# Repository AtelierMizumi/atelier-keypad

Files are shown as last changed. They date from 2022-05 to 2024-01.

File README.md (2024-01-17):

# Atelier6K Keypad Project
The Atelier6K is a 6 keys keypad with 3 additional button designed for playing osu! or to be used as small macropad
+ Hotswapable
+ Per switch RGB + Bottom Case RGB
+ Acrylic Case
+ QMK Firmware with VIA compable (Keybinding, Light Control ...)

# Preview images

## PCB front view



## PCB back view



## Case



+ 7$: Fuse, Led, Switch, Bolts, Keycap, USB C Female connector, Rubber Feet
+ 5$: Atmega32u4
+ 5$: Acrylic Case
+ 3$: PCB printing
+ 2$: USB Cable

$40 to be expected

# Sketch



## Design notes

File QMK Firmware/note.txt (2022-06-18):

Để tự compile cái firmware này:
#1 Copy paste "atelier6k" vào mục keyboards của nơi chứa QMK Firmware
# Vào QMK MSYS gõ qmk compile -kb atelier6k -km default

Nếu biết tự làm firmware rồi, chắc không cần chỉ dẫn thêm. Good Luck!

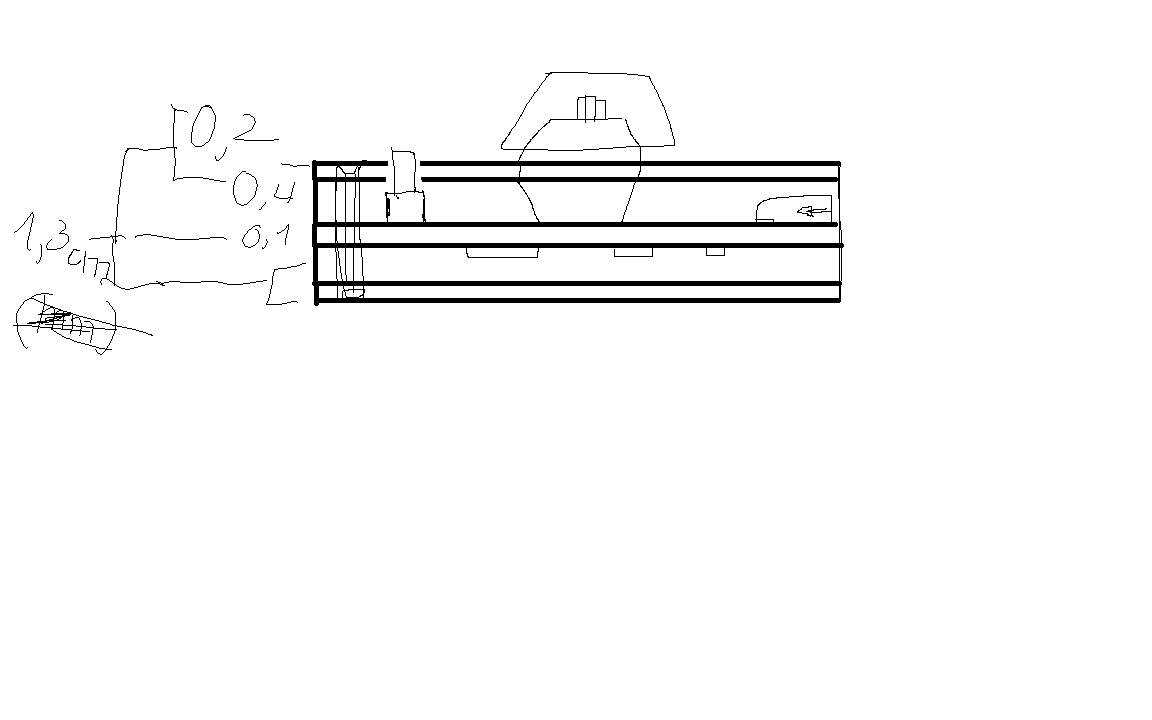
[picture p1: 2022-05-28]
basic sketch lmao.jpg

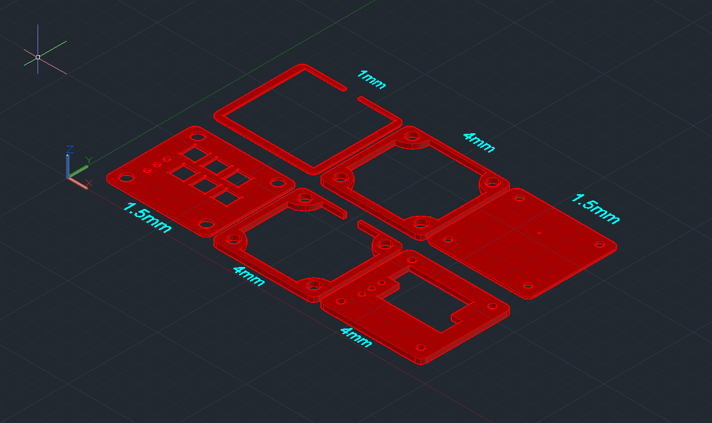
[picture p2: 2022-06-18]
attachment.png

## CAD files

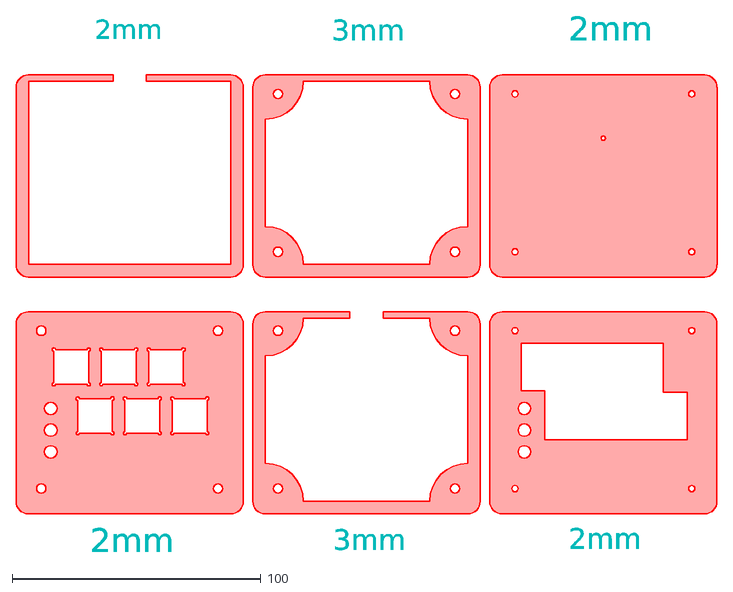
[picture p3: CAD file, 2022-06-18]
Case/Case-Cutout.dxf
2mm
3mm

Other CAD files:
Case/Drawing1.dwg
Case/Case-Cutout.dwg

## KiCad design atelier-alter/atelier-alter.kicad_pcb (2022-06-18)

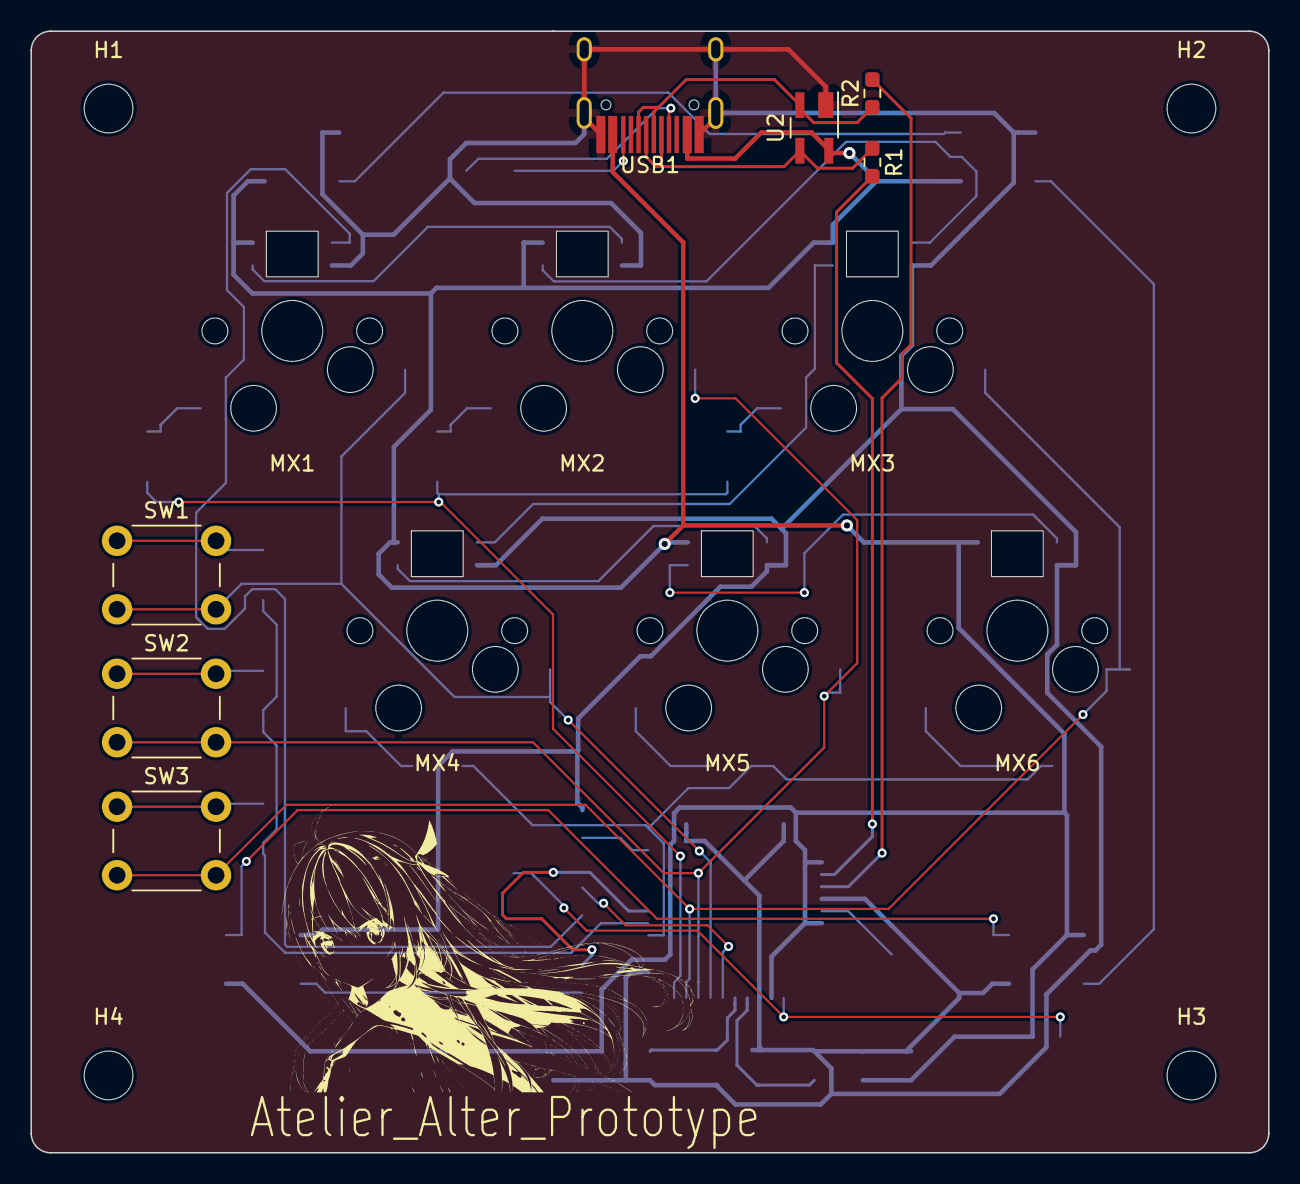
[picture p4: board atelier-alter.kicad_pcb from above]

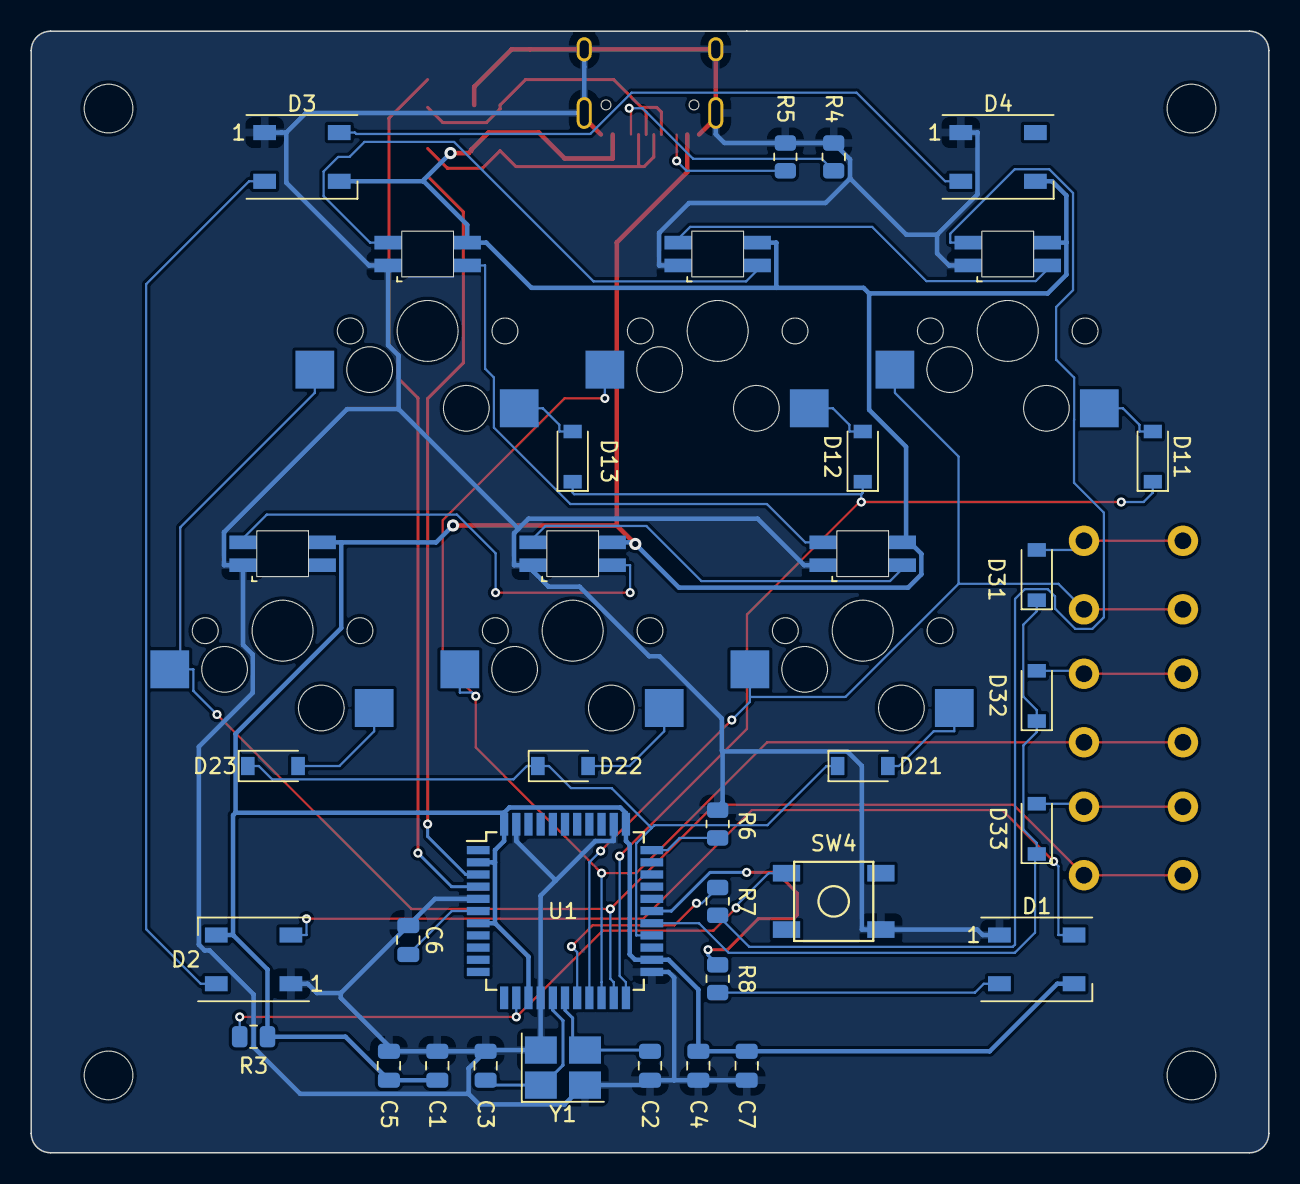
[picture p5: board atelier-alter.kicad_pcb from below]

Board: 2 copper layers, 81.3 x 73.7 mm, 47 parts (29 on the bottom side), 40 nets.

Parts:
Atorie': LOGO; Alter_Drawing
C1, C4, C5: 0.1uF; C_0805_2012Metric
C2, C3: 22pF; C_0805_2012Metric
C6: 1uF; C_0805_2012Metric
C7: 10uF; C_0805_2012Metric
D1, D2, D3, D4: SK6812 / WS2812B; LED_WS2812B_PLCC4_5.0x5.0mm_P3.2mm
D11, D12, D13, D21, D22, D23, D31, D32, D33: SOD-123; D_SOD-123
H1, H2, H3, H4: MountingHole; MountingHole_3.2mm_M3_ISO7380
MX1, MX2, MX3, MX4, MX5, MX6: Cherry_MX_Cherry_MX_RGB; Cherry-MX_PCB-Mounted_LTST-A683CEGBW_Kailh_Socket
R1, R2: 22; R_0603_1608Metric_Pad0.98x0.95mm_HandSolder
R3, R6: 10k; R_0805_2012Metric
R4, R5: 5.1k; R_0805_2012Metric
R7, R8: 300; R_0805_2012Metric
SW1, SW2, SW3: SW_DPST; SW_PUSH_6mm_H13mm
SW4: RESET; SKQG-1155865
U1: ATmega32U4-A; TQFP-44_10x10mm_P0.8mm
U2: PRTR5V0U2X; SOT-143_Handsoldering
USB1: HRO-TYPE-C-31-M-12; HRO-TYPE-C-31-M-12-HandSoldering
Y1: 16Mhz; Crystal_SMD_3225-4Pin_3.2x2.5mm_HandSoldering

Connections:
+5V: C1.1, C4.1, C5.1, C7.1, D1.3 (VDD), D2.3 (VDD), D3.3 (VDD), D4.3 (VDD), MX1.4 (VCC), MX2.4 (VCC), MX3.4 (VCC), MX4.4 (VCC), MX5.4 (VCC), MX6.4 (VCC), R3.2, U1.2 (UVCC), U1.7 (VBUS), U1.14 (VCC), U1.24 (AVCC), U1.34 (VCC), U1.44 (AVCC), U2.4 (VCC), USB1.2 (VBUS), USB1.11 (VBUS)
BackRGB: D1.2 (DIN), R8.2
COL1: MX1.5 (SW1), MX4.5 (SW1), SW1.2, U1.19 (PD1)
COL2: MX2.5 (SW1), MX5.5 (SW1), SW2.2, U1.20 (PD2)
COL3: MX3.5 (SW1), MX6.5 (SW1), SW3.2, U1.21 (PD3)
D12: MX3.3 (DOUT), MX4.2 (DIN)
D+: R2.1, U2.2 (IO1), USB1.6 (DP1), USB1.8 (DP2)
D-: R1.1, U2.3 (IO2), USB1.5 (DN2), USB1.7 (DN1)
GND: C1.2, C2.1, C3.1, C4.2, C5.2, C6.1, C7.2, D1.1 (VSS), D2.1 (VSS), D3.1 (VSS), D4.1 (VSS), MX1.1 (GND), MX2.1 (GND), MX3.1 (GND), MX4.1 (GND), MX5.1 (GND), MX6.1 (GND), R4.1, R5.1, R6.2, SW4.1, U1.5 (UGND), U1.15 (GND), U1.23 (GND), U1.35 (GND), U1.43 (GND), U2.1 (GND), USB1.1 (GND), USB1.12 (GND), USB1.13 (SHIELD), Y1.2, Y1.4
InKeyRGB: MX1.2 (DIN), R7.2
unnamed: C2.2, U1.17 (XTAL1), Y1.3
unnamed: C3.2, U1.16 (XTAL2), Y1.1
unnamed: C6.2, U1.6 (UCAP)
unnamed: D1.4 (DOUT), D2.2 (DIN)
unnamed: D2.4 (DOUT), D3.2 (DIN)
unnamed: D3.4 (DOUT), D4.2 (DIN)
unnamed: D11.2 (A), MX1.6 (SW2)
unnamed: D12.2 (A), MX2.6 (SW2)
unnamed: D13.2 (A), MX3.6 (SW2)
unnamed: D21.2 (A), MX4.6 (SW2)
unnamed: D22.2 (A), MX5.6 (SW2)
unnamed: D23.2 (A), MX6.6 (SW2)
unnamed: D31.2 (A), SW1.1
unnamed: D32.2 (A), SW2.1
unnamed: D33.2 (A), SW3.1
unnamed: MX1.3 (DOUT), MX2.2 (DIN)
unnamed: MX2.3 (DOUT), MX3.2 (DIN)
unnamed: MX4.3 (DOUT), MX5.2 (DIN)
unnamed: MX5.3 (DOUT), MX6.2 (DIN)
unnamed: R1.2, U1.3 (D-)
unnamed: R2.2, U1.4 (D+)
unnamed: R3.1, SW4.2, U1.13 (~RESET)
unnamed: R4.2, USB1.4 (CC1)
unnamed: R5.2, USB1.10 (CC2)
unnamed: R6.1, U1.33 (~HWB/PE2)
unnamed: R7.1, U1.18 (PD0)
unnamed: R8.1, U1.28 (PB4)
ROW1: D11.1 (K), D12.1 (K), D13.1 (K), U1.22 (PD5)
ROW2: D21.1 (K), D22.1 (K), D23.1 (K), U1.26 (PD6)
ROW3: D31.1 (K), D32.1 (K), D33.1 (K), U1.27 (PD7)

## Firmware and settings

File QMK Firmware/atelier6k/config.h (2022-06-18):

/*
Copyright 2012 Jun Wako <wakojun@gmail.com>

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
You should have received a copy of the GNU General Public License
along with this program.  If not, see <http://www.gnu.org/licenses/>.
*/

#pragma once

#include "config_common.h"

/* USB Device descriptor parameter */
#define VENDOR_ID       0xFEED
#define PRODUCT_ID      0x6060
#define DEVICE_VER      0x0001
#define MANUFACTURER    thuanc177
#define PRODUCT         alter6k
#define DESCRIPTION     The Alter6k keypad

/* key matrix size */
#define MATRIX_ROWS 3
#define MATRIX_COLS 3

/* key matrix pins */
#define MATRIX_ROW_PINS { D5, D6, D7 }
#define MATRIX_COL_PINS { D1, D2, D3 }
#define UNUSED_PINS { B0, B1, B2, B3, B5, B6, B7, C6, C6, D4, E6, F0, F1, F4, F5, F6, F7  }

/* COL2ROW or ROW2COL */
#define DIODE_DIRECTION COL2ROW

/* number of backlight levels */
#define BACKLIGHT_PIN B4
#define BACKLIGHT_LEVELS 8

/* Set 0 if debouncing isn't needed */
#define DEBOUNCING_DELAY 5

/* Mechanical locking support. Use KC_LCAP, KC_LNUM or KC_LSCR instead in keymap */
#define LOCKING_SUPPORT_ENABLE

/* Locking resynchronize hack */
#define LOCKING_RESYNC_ENABLE

/* key combination for command */
#define IS_COMMAND() ( \
    keyboard_report->mods == (MOD_BIT(KC_LSHIFT) | MOD_BIT(KC_RSHIFT)) \
)

/* prevent stuck modifiers */
#define PREVENT_STUCK_MODIFIERS

/*Extra stuffs I added myself */
#define USB_POLLING_INTERVAL_MS 1
#define FORCE_NKRO
#define BOOTMAGIC_LITE_ROW 0
#define BOOTMAGIC_LITE_COLUMN 0

/*RGB config and shits*/
#define RGB_DI_PIN D0
#define RGBLIGHT_ANIMATIONS
#define RGBLED_NUM 6
#define RGBW
#define RGBLIGHT_HUE_STEP 12
#define RGBLIGHT_SAT_STEP 25
#define RGBLIGHT_VAL_STEP 8
#define RGBLIGHT_EFFECT_BREATHING
#define RGBLIGHT_EFFECT_RAINBOW_MOOD
#define RGBLIGHT_EFFECT_RAINBOW_SWIRL
#define RGBLIGHT_EFFECT_GRADIENT
#define RGBLIGHT_DEFAULT_MODE RGBLIGHT_MODE_RAINBOW_MOOD

#define USB_MAX_POWER_CONSUMPTION 500

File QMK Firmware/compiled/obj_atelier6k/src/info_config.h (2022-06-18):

// Copyright 2022 QMK
// SPDX-License-Identifier: GPL-2.0-or-later

/*******************************************************************************
  88888888888 888      d8b                .d888 d8b 888               d8b
      888     888      Y8P               d88P"  Y8P 888               Y8P
      888     888                        888        888
      888     88888b.  888 .d8888b       888888 888 888  .d88b.       888 .d8888b
      888     888 "88b 888 88K           888    888 888 d8P  Y8b      888 88K
      888     888  888 888 "Y8888b.      888    888 888 88888888      888 "Y8888b.
      888     888  888 888      X88      888    888 888 Y8b.          888      X88
      888     888  888 888  88888P'      888    888 888  "Y8888       888  88888P'
                                                        888                 888
                                                        888                 888
                                                        888                 888
     .d88b.   .d88b.  88888b.   .d88b.  888d888 8888b.  888888 .d88b.   .d88888
    d88P"88b d8P  Y8b 888 "88b d8P  Y8b 888P"      "88b 888   d8P  Y8b d88" 888
    888  888 88888888 888  888 88888888 888    .d888888 888   88888888 888  888
    Y88b 888 Y8b.     888  888 Y8b.     888    888  888 Y88b. Y8b.     Y88b 888
     "Y88888  "Y8888  888  888  "Y8888  888    "Y888888  "Y888 "Y8888   "Y88888
         888
    Y8b d88P
     "Y88P"
*******************************************************************************/

#pragma once

#ifndef BACKLIGHT_PIN
#   define BACKLIGHT_PIN B4
#endif // BACKLIGHT_PIN

#ifndef DEVICE_VER
#   define DEVICE_VER 0x0001
#endif // DEVICE_VER

#ifndef DESCRIPTION
#   define DESCRIPTION "atelier6k"
#endif // DESCRIPTION

#ifndef DIODE_DIRECTION
#   define DIODE_DIRECTION COL2ROW
#endif // DIODE_DIRECTION

#ifndef MANUFACTURER
#   define MANUFACTURER thuanc177
#endif // MANUFACTURER

#ifndef RGB_DI_PIN
#   define RGB_DI_PIN D0
#endif // RGB_DI_PIN

#ifndef RGBLED_NUM
#   define RGBLED_NUM 6
#endif // RGBLED_NUM

#ifndef RGBLIGHT_HUE_STEP
#   define RGBLIGHT_HUE_STEP 12
#endif // RGBLIGHT_HUE_STEP

#ifndef RGBLIGHT_SAT_STEP
#   define RGBLIGHT_SAT_STEP 25
#endif // RGBLIGHT_SAT_STEP

#ifndef RGBLIGHT_VAL_STEP
#   define RGBLIGHT_VAL_STEP 8
#endif // RGBLIGHT_VAL_STEP

#ifndef PRODUCT
#   define PRODUCT alter6k
#endif // PRODUCT

#ifndef PRODUCT_ID
#   define PRODUCT_ID 0x6060
#endif // PRODUCT_ID

#ifndef VENDOR_ID
#   define VENDOR_ID 0xFEED
#endif // VENDOR_ID

#ifndef USB_MAX_POWER_CONSUMPTION
#   define USB_MAX_POWER_CONSUMPTION 500
#endif // USB_MAX_POWER_CONSUMPTION

#ifndef USB_POLLING_INTERVAL_MS
#   define USB_POLLING_INTERVAL_MS 1
#endif // USB_POLLING_INTERVAL_MS

#ifndef MATRIX_COLS
#   define MATRIX_COLS 3
#endif // MATRIX_COLS

#ifndef MATRIX_ROWS
#   define MATRIX_ROWS 3
#endif // MATRIX_ROWS


#ifndef MATRIX_COL_PINS
#   define MATRIX_COL_PINS { D1, D2, D3 }
#endif // MATRIX_COL_PINS


#ifndef MATRIX_ROW_PINS
#   define MATRIX_ROW_PINS { D5, D6, D7 }
#endif // MATRIX_ROW_PINS

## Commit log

2022-05-25 add main things
    [atelier-alter.kicad_pcb, atelier-alter.kicad_sch]
2022-05-26 da route thu nghiem xong xuoi
    [atelier-alter.kicad_pcb]
2022-05-27 redrawn lan 3, them vai chuc nang
    [atelier-alter-27-5-2022.dsn, atelier-alter-28-5-2022.dsn, atelier-alter.kicad_pcb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]
2022-05-27 tham khao them tu board vcl6k
2022-05-27 kaka, rat manh
    [atelier-alter-27-5-2022.dsn, atelier-alter-28-5-2022.dsn, atelier-alter.kicad_pcb]
2022-05-27 add essentials
    [atelier-alter-28-5-2022.dsn, atelier-alter.kicad_pcb, atelier-alter.kicad_sch]
2022-05-27 update footprint, route lai mach, giam manh so luong vias
    [atelier-alter-28-5-2022.dsn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]
2022-05-27 xuat file gerber de in
    [atelier-alter-28-5-2022.dsn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]
2022-05-28 add M2 mounting hole
    [Drawing1.dwg, Plates.kicad_pcb, Plates.kicad_sch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]
2022-05-28 rework mot chut
    [Drawing1.dwg, atelier-alter-28-5-2022.dsn, atelier-alter.kicad_pcb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]
2022-05-28 update doc tao di . md
2022-05-28 xuat file gerber dong bo
    [Plates.kicad_pcb, Plates.kicad_sch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]
2022-05-31 small tweaks, done drawing the case
    [Drawing1.dwg, atelier-alter-28-5-2022.dsn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]
2022-06-02 minor updates here and there
    [Drawing1.dwg, atelier-alter-28-5-2022.dsn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]
2022-06-03 decided to nuke all led capacitor
    [Drawing1.dwg, atelier-alter-28-5-2022.dsn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]
2022-06-03 van la doc tao . md
2022-06-04 add qmp firmware files
    [Drawing1.dwg]
2022-06-04 update pcb + qmk firmware
    [atelier-alter-28-5-2022.dsn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]
2022-06-18 final commit for rev 0.
    [Drawing1.dwg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]

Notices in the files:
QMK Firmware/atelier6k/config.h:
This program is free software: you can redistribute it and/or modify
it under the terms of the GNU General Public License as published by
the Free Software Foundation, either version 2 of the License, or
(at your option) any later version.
